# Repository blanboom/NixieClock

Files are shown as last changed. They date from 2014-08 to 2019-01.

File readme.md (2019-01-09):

## 简介

支持蓝牙 4.0 的辉光管时钟，主控芯片为 STC15F2K60S2，主要特性如下：

- 六位数字显示
- 每隔 10 分钟循环显示所有数字，防止阴极中毒
- 四个氖灯，可独立控制，用于显示冒号、小数点等
- 每个辉光管下安装有一个全彩 LED，可调节 LED 颜色
- 支持闹钟
- 支持夜间模式，夜间自动关闭辉光管
- 可通过蓝牙对时钟进行设置
- 采用 SD2405ALPI 实时时钟，掉电后时间不会丢失
- 可通过蓝牙对时钟进行控制
- 带有自定义显示模式，可通过蓝牙显示任意数字（例如温度、网速等）

辉光管时钟照片

## 开发环境

- Keil C51 µVision V4.72.9.0
- Altium Designer 14
- 蓝牙模块波特率已预先设置为 115200bps

## 蓝牙指令

*  TIMShhmmss    -  设置时间，hhmmss 为 24 时制时间
*  TIMAhhmmss    -  设置闹钟，hhmmss 为 24 时制时间
*  TIMLggrrbb    -  设置 LED 颜色，ggrrbb 为 LED 的 RGB 颜色
*  TIMMx         -  打开/关闭闹钟，x = 1 时打开，x = 0 时关闭
*  TIMDxxxxxxdd  -  进入自定义显示模式并显示内容，xxxxxx 为要显示的数字（支持空格），dd控制四个点的显示，范围为 0 ~ 15，其对应的四位二进制数中的各位分别代表四个点的状态（1 为亮，0 为灭）
*  TIMT          -  切换回时钟模式
*  TIMNx         -  夜间模式开关，x = 0 时关闭，x = 1 时打开。打开夜间模式后，凌晨 1 点到早上 6 点辉光管不显示时间

## 该版本硬件上的缺陷

* 蓝牙模块 和 排针引出的串口接口 均使用了 UART1，但 STC15F2K60S2 有两组 UART 接口，没能充分利用该单片机的片上资源。因此如果想要通过串口外接其他设备/模块，同时又要使用蓝牙功能，在程序上可能会麻烦一些。
* 高压和低压部分没有通过光耦等形式相隔离，电路故障时低压部分可能会损坏。
* PCB 布线不够整齐，元器件排布不太紧凑。另外六个辉光管的位置向下移动一点，应该会更美观。
* 蓝牙天线下有覆铜，对信号强度有不利影响。

## 感谢

在制作的过程中，[NixieClock.org](http://www.nixieclock.org) 中的文章给我带来了很大的帮助。在这里，对博主严泽远表示感谢。

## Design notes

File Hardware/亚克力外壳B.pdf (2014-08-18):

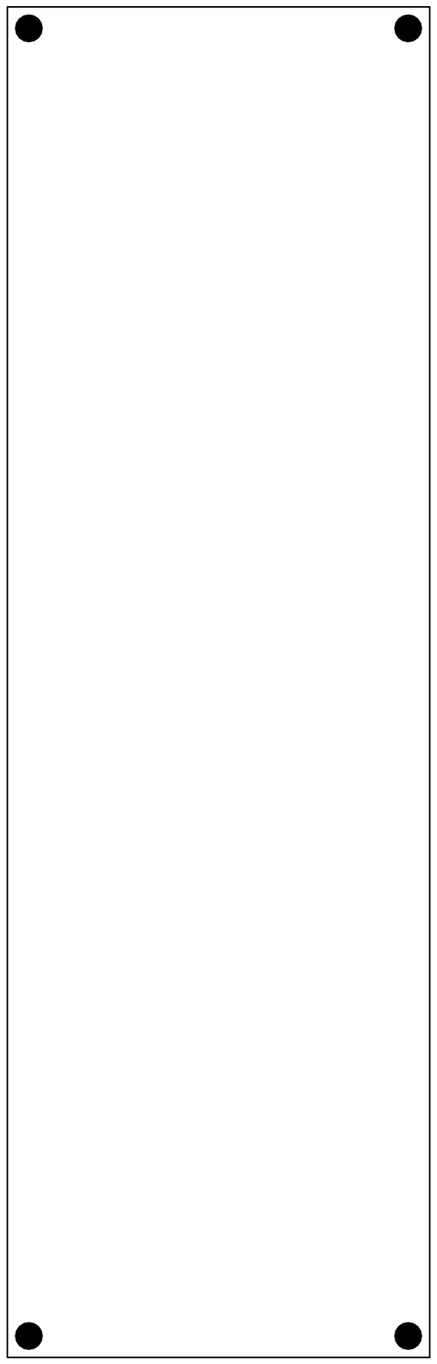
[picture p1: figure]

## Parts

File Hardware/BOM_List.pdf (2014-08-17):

QS30-1辉光管时钟材料清单

描述 | 数量

插接件
DC-044插座（2.1 - 5.5mm） | 1
4-pin弯排针 | 1

芯片
STC15F2K60S2 LQFP44 | 1
SD2405ALPI 实时时钟 | 1
RF-BM-S02 蓝牙模块 | 1
MC34063ADR2G SOP8 | 1
78M05 | 1
LPD6803 SOP16 | 1
XC6206 SOT23 | 1
HV57708PG | 1

二三极管
9014 三极管 SOT23 | 1
A42(MMBTA42LT1-D) 三极管 SOT23 | 4
1N4007 M7 二极管 贴片 | 1
FR-107 RS1M 二极管 贴片 | 1
75V 0.5W 稳压二极管 1206 | 1
IRF630 TO-263 | 1

电容电阻
0.33R 0805 | 1
100R 0805 | 1
330R 0805 | 3
510R 0805 | 4
1K 0805 | 1
8.2K 0805 | 1
20K 0805 | 6
33K 0805 | 4
240K 0805 | 4
1.1M 0805 | 1
100pF 0805 | 5
1nF 0805 | 1
0.1uF 0805 | 5
4.7uF 250V 1812 | 1
10uF 16V 钽电容 1206 | 1
470uF 16V 贴片钽电容 E型 7343 477C | 1

声光器件

无源蜂鸣器 5V | 1
RGB LED 5050 | 6
QS30-1 辉光管及管座 | 6
氖灯 | 4

其他
330uH 贴片电感 12*12*7 | 1
1A自恢复保险丝 1206 | 1
12V电源 | 1

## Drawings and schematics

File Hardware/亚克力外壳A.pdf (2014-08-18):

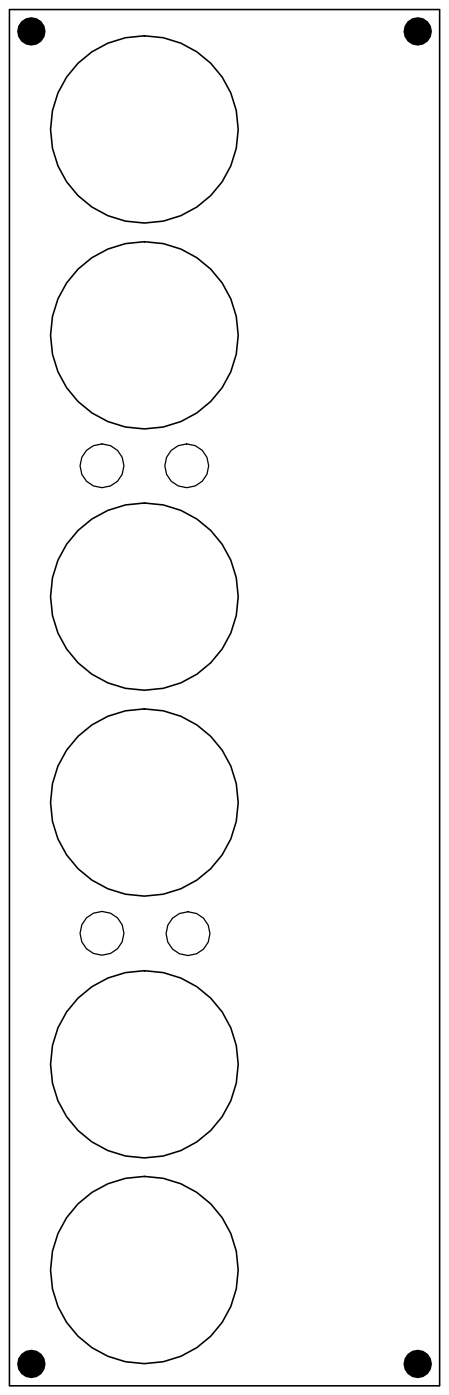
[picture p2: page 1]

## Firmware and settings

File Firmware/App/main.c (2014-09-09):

/**
 * 主程序
 * 作者：    Blanboom
 * 最后更新：2014-08-18
 * http://blanboom.org
 */

#include "Display.h"
#include "TimeUpdate.h"
#include "app.h"
#include "delay.h"
#include "timer.h"
#include "Bluetooth.h"
#include "RTC.h"
#include "Sound.h"

// 储存当前时间、闹钟、工作模式的全局变量，在 "app.h" 中声明
// 时间
uint8_t hour = 12;
uint8_t minute = 59;
uint8_t second = 59;
uint8_t per25ms = 0;
// 闹钟
uint8_t hour_alarm = 12;
uint8_t minute_alarm = 1;
uint8_t second_alarm = 1;
uint8_t alarmEnable = 0;
// 夜间模式
uint8_t sleepMode = 1;
// 自定义显示模式下，要显示的数字
uint8_t numbertoDisplay[6] = {0, 0, 0, 0, 0, 0};
// 模式，有时钟模式和自定义显示模式
uint8_t mode = MODE_CLOCK;


int main(void)
{
	// 各种初始化
	uint8_t second_tmp = 0;
	EA = 0;
	bluetoothInit();
	displayInit();
	timerInit();
	soundInit();
	Delay_ms(250);
	Delay_ms(250);
	Delay_ms(250);
	Delay_ms(250);
	getTime();
	EA = 1;
	
	
  while(1)
	{
		if(second_tmp != second && mode == MODE_CLOCK)  // 时钟模式，每秒刷新一次显示
		{
			if(sleepMode && hour >= 1 && hour <= 6)
			{
				displayUserNumber("     ");   // 夜间模式，不显示数字
			}
			else
			{
				displayTime();
			}
			
			if(second % 2 == 0)
			{
				displayDots(DISPLAY_DOTS_ALL);
			}
			else
			{
				displayDots(DISPLAY_DOTS_NONE);
			}
			second_tmp = second;
		}
		
		if(second_tmp != second && mode == MODE_DISPLAY)  // 自定义显示模式，每秒刷新一次
		{
			displayUserNumber(numbertoDisplay);
			second_tmp = second;
    }
		
		bluetoothCheck();  // 蓝牙检测
		
		alarmDispatcher(); // 闹钟检测与处理
		
		if((minute % 10 == 0) && (second < 10))  // 每隔 10 分钟循环显示所有数字，防止阴极中毒
		{
			displayNumber(000000);
			Delay_ms(50);
			displayNumber(111111);
			Delay_ms(50);
			displayNumber(222222);
			Delay_ms(50);
			displayNumber(333333);
			Delay_ms(50);
			displayNumber(444444);
			Delay_ms(50);
			displayNumber(555555);
			Delay_ms(50);
			displayNumber(666666);
			Delay_ms(50);
			displayNumber(777777);
			Delay_ms(50);
			displayNumber(888888);
			Delay_ms(50);
			displayNumber(999999);
			Delay_ms(50);
		}
	}
	//return 0;
}

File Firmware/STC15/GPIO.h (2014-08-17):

#ifndef	__GPIO_H
#define	__GPIO_H

#include	"config.h"

#define	GPIO_PullUp		0	//上拉准双向口
#define	GPIO_HighZ		1	//浮空输入
#define	GPIO_OUT_OD		2	//开漏输出
#define	GPIO_OUT_PP		3	//推挽输出

#define	GPIO_Pin_0		0x01	//IO引脚 Px.0
#define	GPIO_Pin_1		0x02	//IO引脚 Px.1
#define	GPIO_Pin_2		0x04	//IO引脚 Px.2
#define	GPIO_Pin_3		0x08	//IO引脚 Px.3
#define	GPIO_Pin_4		0x10	//IO引脚 Px.4
#define	GPIO_Pin_5		0x20	//IO引脚 Px.5
#define	GPIO_Pin_6		0x40	//IO引脚 Px.6
#define	GPIO_Pin_7		0x80	//IO引脚 Px.7
#define	GPIO_Pin_All	0xFF	//IO所有引脚
	
#define	GPIO_P0			0		//
#define	GPIO_P1			1
#define	GPIO_P2			2
#define	GPIO_P3			3
#define	GPIO_P4			4
#define	GPIO_P5			5


typedef struct
{
	u8	Mode;		//IO模式,  		GPIO_PullUp,GPIO_HighZ,GPIO_OUT_OD,GPIO_OUT_PP
	u8	Pin;		//要设置的端口	
} GPIO_InitTypeDef;

u8	GPIO_Inilize(u8 GPIO, GPIO_InitTypeDef *GPIOx);

#endif

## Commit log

2014-08-18 添加亚克力外壳图纸
2014-08-20 添加蓝牙模块波特率
2014-08-20 增加 硬件部分存在的缺陷
2014-08-20 修改 排版与标题层级
2014-08-20 添加 感谢
2014-08-20 移除 垃圾文件
2014-08-20 更新 作品特色
2014-08-20 更新 将 PCB 文件夹改名为 Hardware
    [NixieClock_V1.PrjPCB, PCB.PcbDoc, PCBLIB.PcbLib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]
2014-09-09 移除开机提示音
2014-09-09 [添加功能] 自定义显示模式可显示空格
2014-09-09 [添加功能] 增加夜间模式
2014-09-09 更新 readme
2019-01-09 更新图片
